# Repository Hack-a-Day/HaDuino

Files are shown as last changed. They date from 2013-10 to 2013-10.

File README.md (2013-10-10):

<center><H1>The HaDuino</H1>
<H3>Hackaday's own Arduino-compatible AVR development board</H3></center>
<hr>

Under our new ownership, Hackaday is now able to bring you the latest and the greatest Open Hardware projects 
designed <i>completely in house</i>. For our first such experimentation in our own custom hardware, we decided
to build what we love: an Arduino-compatable development board that blinks a LED.<p>

However, following a cursory review of existing development boards, we were somewhat dejected; we realized everything
that could be done with an Arduino board had already been done. After some serious drin^H^H^H^Hthinking, the brains
behind Hackaday came up with an entirely new paradigm for what development boards can do.<p>

<H3>It's a freakin' bottle opener<H3><p>

Really, how sweet is that? I mean just look at this thing:



Actually, it's pretty sucky as a bottle opener. We ended up breaking the first one we tested. Nevertheless, in the
spirit of open hardware, we're giving out our files and hoping some of you can improve on it. Maybe you want to
remove the pin headers and replace them with LEDs? Maybe you want to make the bottle opener actually work. That's all
fine with us. just <a href="http://hackaday.com/contact-hack-a-day/">drop us a note on our tip line</a> if you build
your own.

Oh, the back silk screen is pretty sweet:



So there you go. Schematic and BOM are in the PDF, if you get a board made (I'm sharing it 
<a href="http://oshpark.com/shared_projects/lNlBlB2y">at OSH Park</a>. It's about $30 for three boards) you most likely
already have the components to make this lying around in your parts bin. Gerbers are up as well, do with them as
you please.

Rock on.

PS: This is totally not an Arduino (Hi Massimo! Like your HaD t-shirt?) and anyone calling it that will face the fury
of a hundred goose-sized geese.

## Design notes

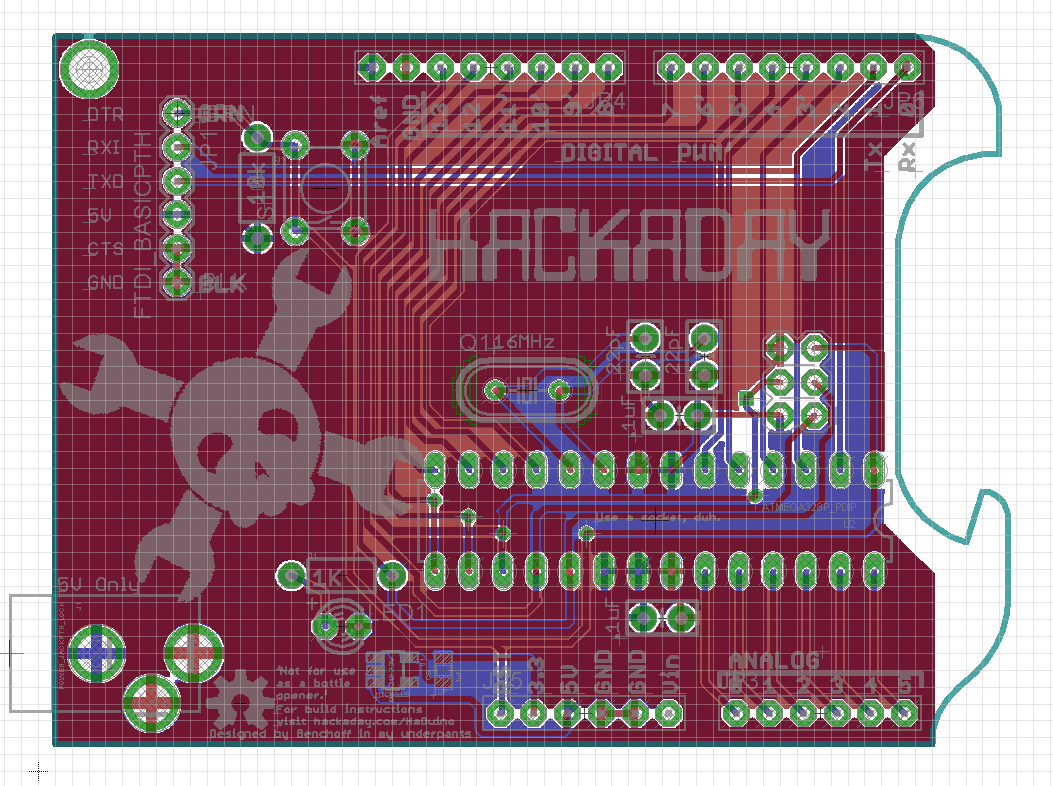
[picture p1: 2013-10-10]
BoardTop.png

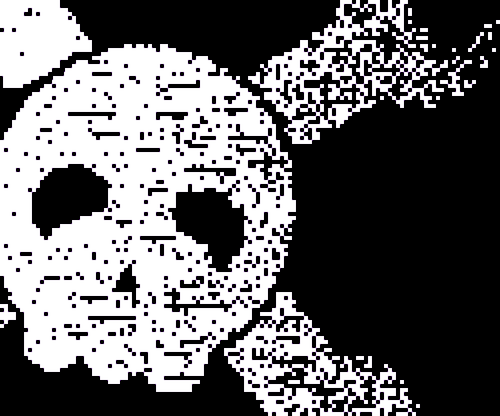
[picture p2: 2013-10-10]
Silk.png

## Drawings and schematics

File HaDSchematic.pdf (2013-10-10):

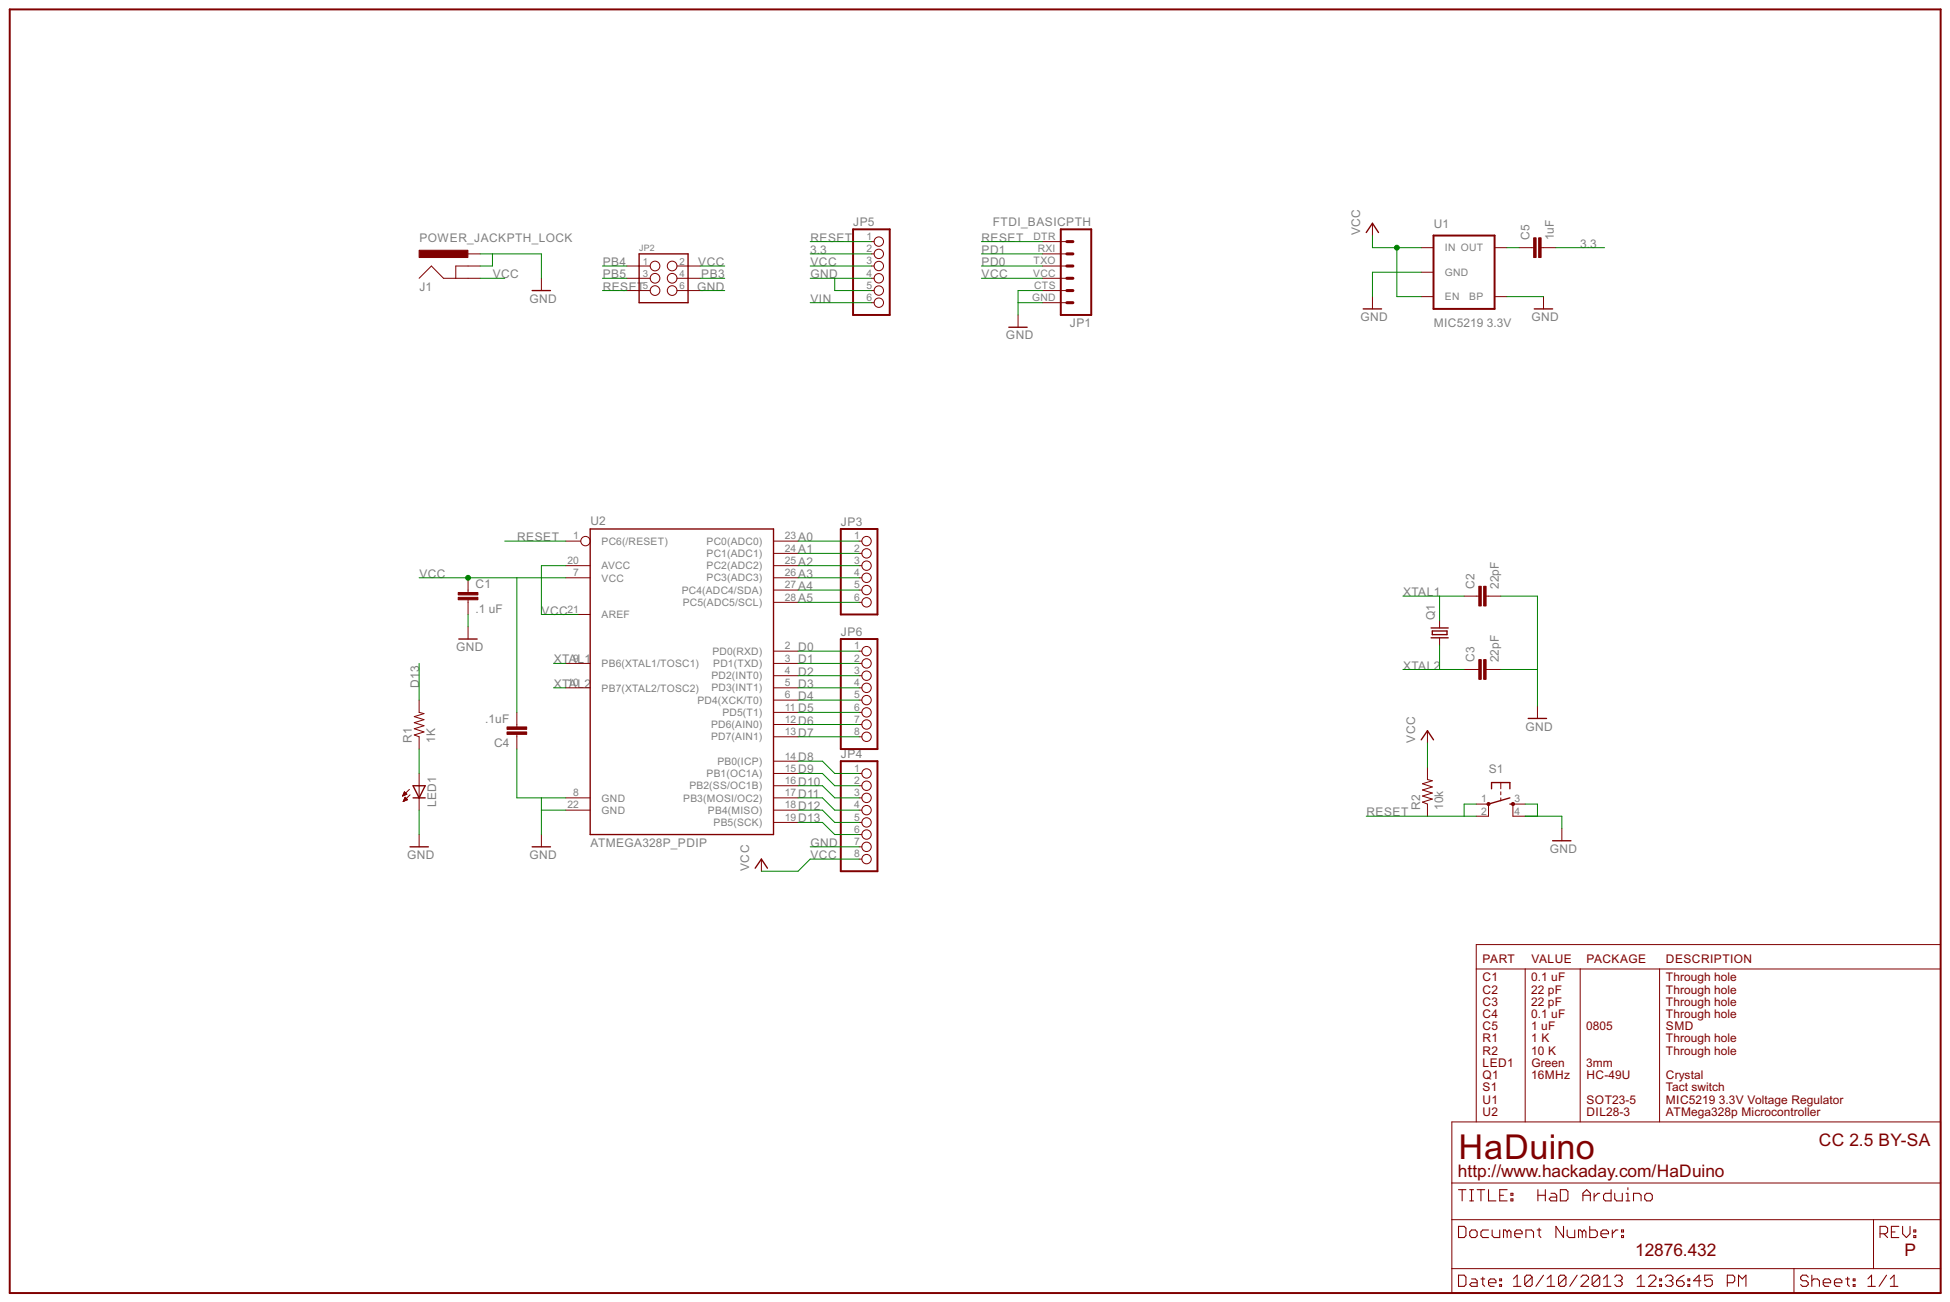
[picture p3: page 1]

Through hole Through hole

http://www.hackaday.com/HaDuino

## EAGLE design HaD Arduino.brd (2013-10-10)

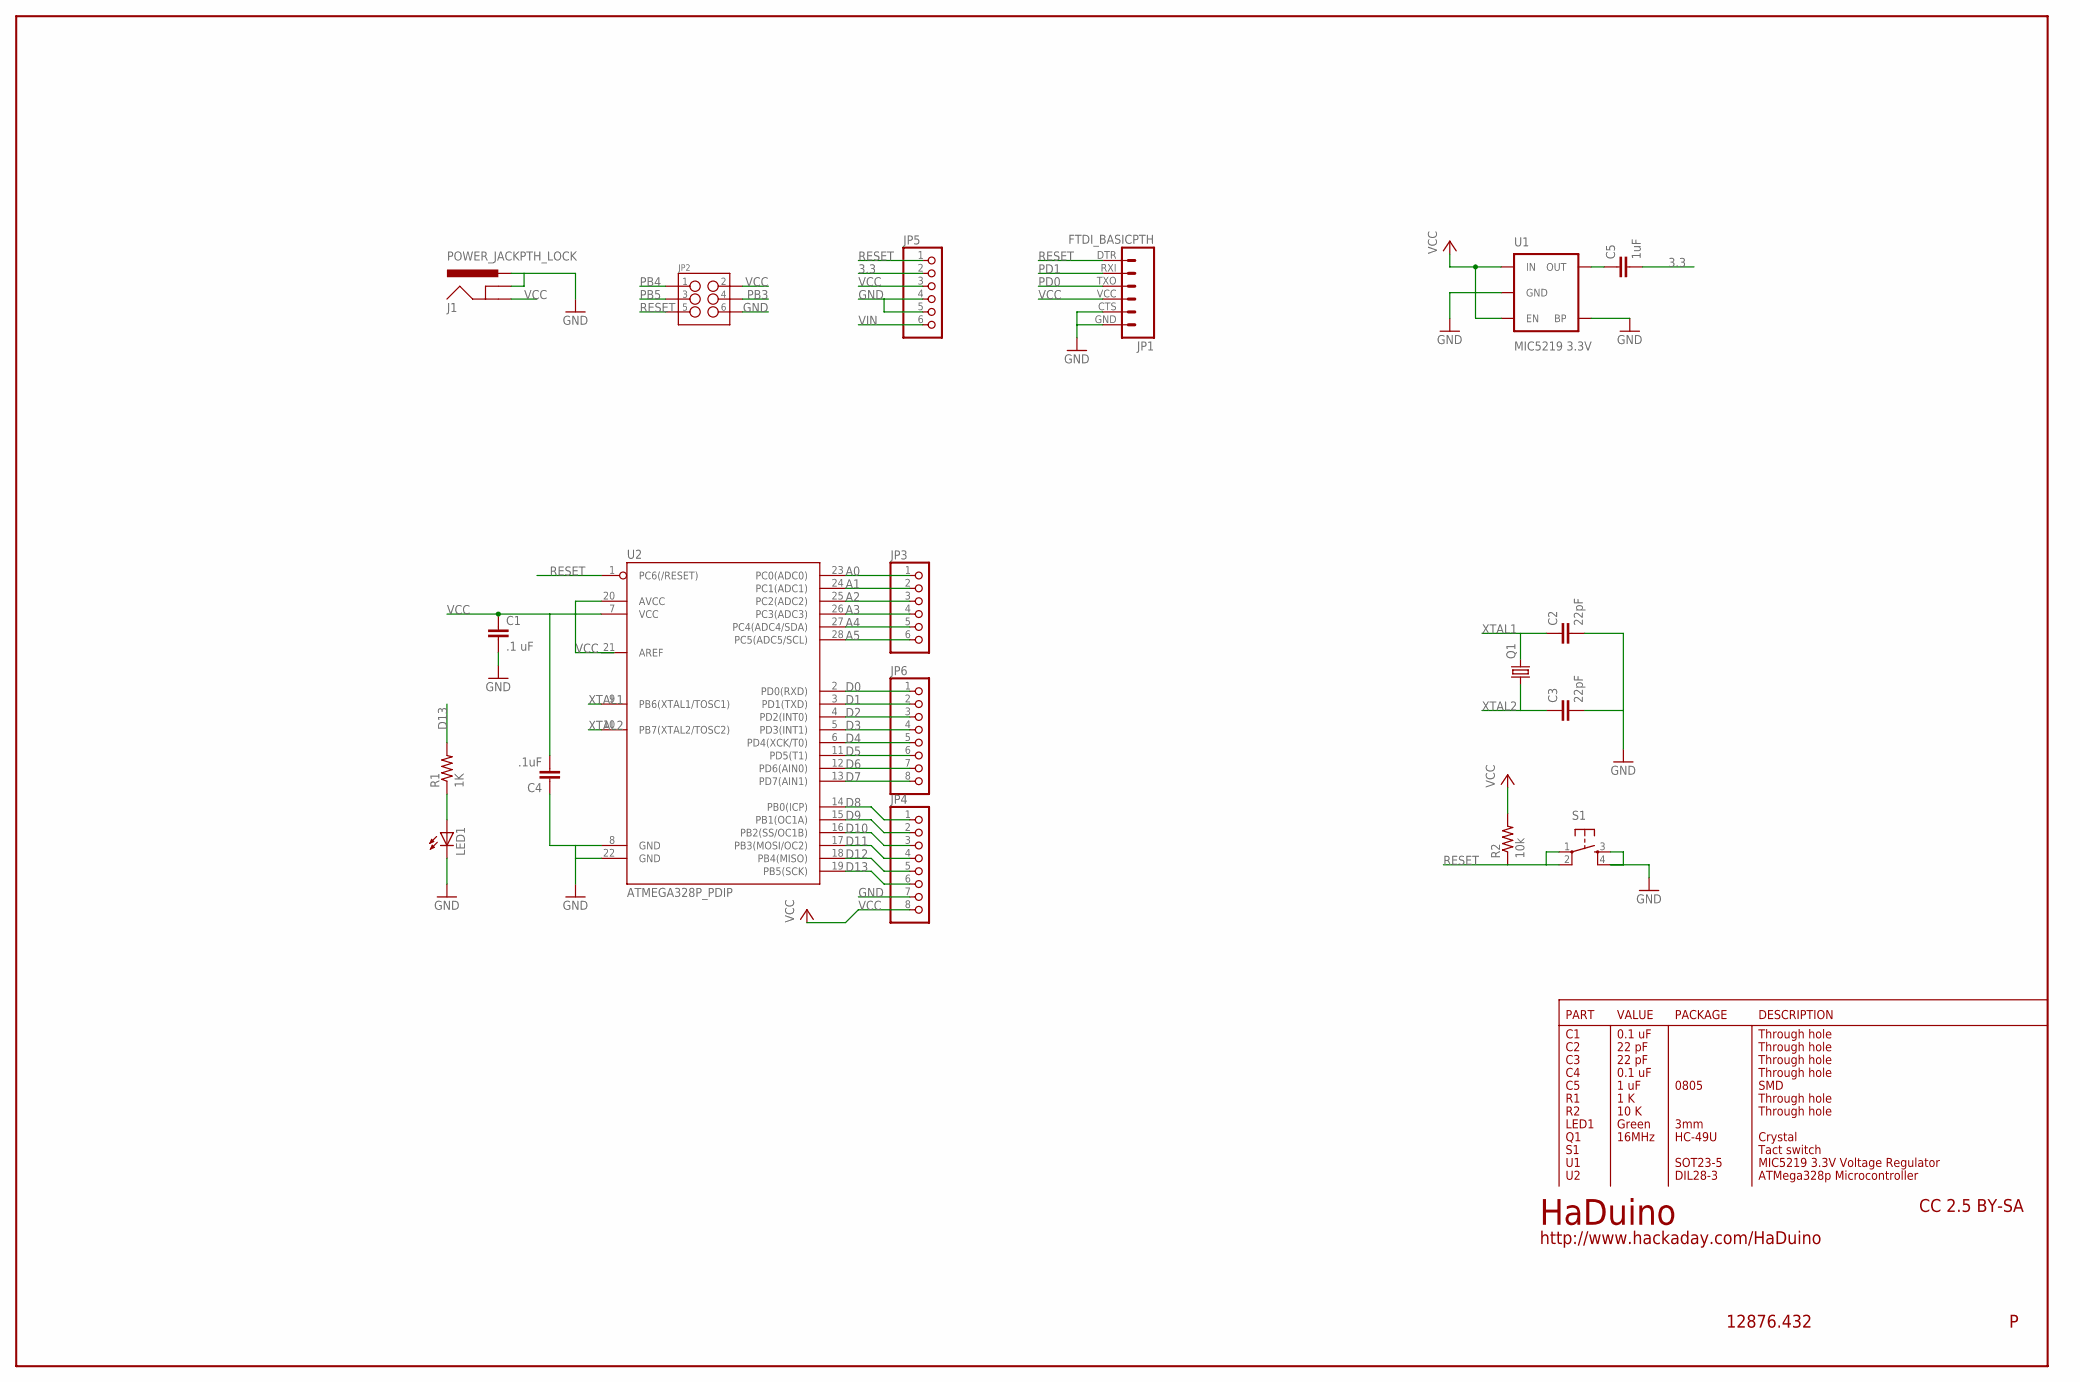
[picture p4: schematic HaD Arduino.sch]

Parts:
C1: .1 uF; CAP-PTH-SMALL-KIT
C2, C3: 22pF; CAP-PTH-SMALL-KIT
C4: .1uF; CAP-PTH-SMALL-KIT
C5: 1uF; 0805
J1: POWER_JACKPTH_LOCK; POWER_JACK_PTH_LOCK
JP1: FTDI_BASICPTH; FTDI_BASIC
JP2: M03X2POGO_PINS; 2X3_POGO
JP3, JP5: PINHD-1X6B; 1X06-BIG
JP4, JP6: PINHD-1X8BIG; 1X08-BIG
LED1: LED3MM
Q1: CRYTALHC49U-V; HC49U-V
R1: 1K; AXIAL-0.3-KIT
R2: 10k; AXIAL-0.3-KIT
S1: TAC_SWITCHPTH; TACTILE-PTH
U1: MIC5219 3.3V; SOT23-5
U2: ATMEGA328P_PDIP; DIL28-3

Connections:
3.3: C5.2, JP5.2
A0: JP3.1, U2.23 (PC0(ADC0))
A1: JP3.2, U2.24 (PC1(ADC1))
A2: JP3.3, U2.25 (PC2(ADC2))
A3: JP3.4, U2.26 (PC3(ADC3))
A4: JP3.5, U2.27 (PC4(ADC4/SDA))
A5: JP3.6, U2.28 (PC5(ADC5/SCL))
D0: JP6.1, U2.2 (PD0(RXD))
D1: JP6.2, U2.3 (PD1(TXD))
D2: JP6.3, U2.4 (PD2(INT0))
D3: JP6.4, U2.5 (PD3(INT1))
D4: JP6.5, U2.6 (PD4(XCK/T0))
D5: JP6.6, U2.11 (PD5(T1))
D6: JP6.7, U2.12 (PD6(AIN0))
D7: JP6.8, U2.13 (PD7(AIN1))
D8: JP4.1, U2.14 (PB0(ICP))
D9: JP4.2, U2.15 (PB1(OC1A))
D10: JP4.3, U2.16 (PB2(SS/OC1B))
D11: JP4.4, U2.17 (PB3(MOSI/OC2))
D12: JP4.5, U2.18 (PB4(MISO))
D13: JP4.6, R1.P$2 (2), U2.19 (PB5(SCK))
GND: C1.2, C2.2, C3.2, C4.1, J1.GNDBREAK, J1.PWR, JP1.CTS (5), JP1.GND (6), JP2.P$6 (6), JP4.7, JP5.4, JP5.5, LED1.K (C), S1.3, S1.4, U1.2 (GND), U1.4 (BP), U2.8 (GND), U2.22 (GND)
unnamed: LED1.A, R1.P$1 (1)
unnamed: C5.1, U1.5 (OUT)
PB3: JP2.P$4 (4)
PB4: JP2.P$1 (1)
PB5: JP2.P$3 (3)
PD0: JP1.TXO (3)
PD1: JP1.RXI (2)
RESET: JP1.DTR (1), JP2.P$5 (5), JP5.1, R2.P$1 (1), S1.1, S1.2, U2.1 (PC6(/RESET))
VCC: C1.1, C4.2, J1.GND, JP1.VCC (4), JP2.P$2 (2), JP4.8, JP5.3, R2.P$2 (2), U1.1 (IN), U1.3 (EN), U2.7 (VCC), U2.20 (AVCC), U2.21 (AREF)
VIN: JP5.6
XTAL1: C2.1, Q1.2, U2.9 (PB6(XTAL1/TOSC1))
XTAL2: C3.1, Q1.1, U2.10 (PB7(XTAL2/TOSC2))

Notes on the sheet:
VALUE
PART
PACKAGE
DESCRIPTION
LED1
Green
3mm
16MHz
HC-49U
Through hole
0.1 uF
22 pF
1 uF
0805
SMD
1 K
10 K
Crystal
Tact switch
SOT23-5
MIC5219 3.3V Voltage Regulator
ATMega328p Microcontroller
DIL28-3
CC 2.5 BY-SA
HaDuino
http://www.hackaday.com/HaDuino
12876.432

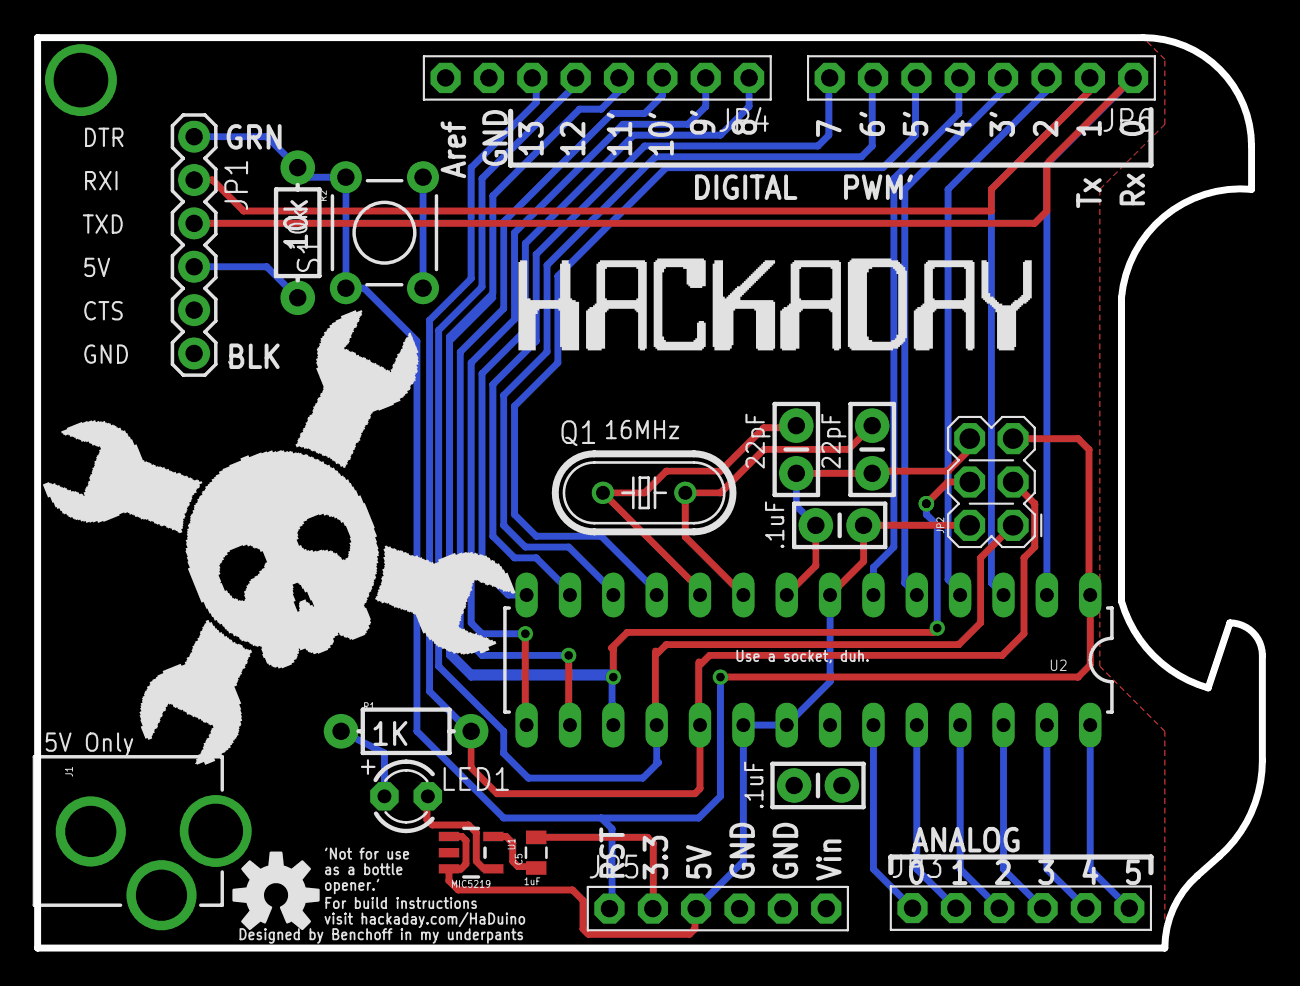
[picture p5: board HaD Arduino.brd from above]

Board: 2 copper layers, 71.8 x 53.3 mm, 20 parts (0 on the bottom side), 28 nets.

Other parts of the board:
U$1: OSHW-LOGO-M

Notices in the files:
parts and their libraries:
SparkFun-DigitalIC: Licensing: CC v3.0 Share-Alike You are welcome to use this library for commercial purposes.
